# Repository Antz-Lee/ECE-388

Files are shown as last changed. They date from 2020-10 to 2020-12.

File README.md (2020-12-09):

# Volt-Meter-Project
Creating a voltmeter that displays the input voltage on an LCD display by using an ATmega328pb chip. The link below is a youtube video that focuses 
on the structure behind building a Voltmeter with an Atmega328PB microchip. The video also contains a live demo of the voltmeter that displays the 
voltage value of 9V batteries connected in series with a max voltage of 36Volts. 

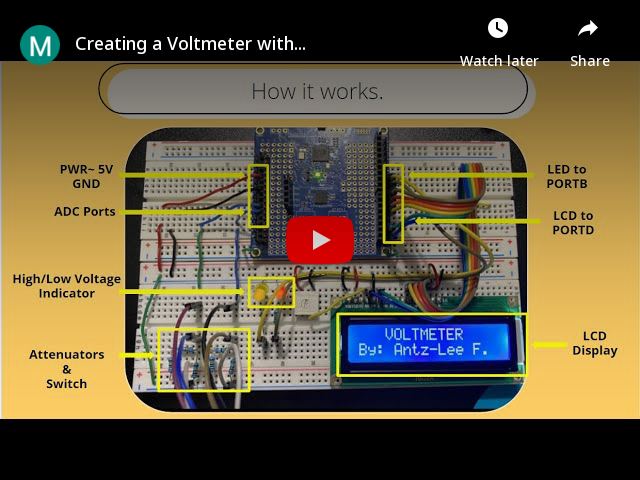
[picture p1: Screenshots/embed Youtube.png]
Watch the video (https://www.youtube.com/watch?v=6kzmSNdP678&ab_channel=Antz-LeeFrancois)


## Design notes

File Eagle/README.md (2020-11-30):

# Schematic and Board Layout
The schematic layout created on the EAGLE program. In regards, to the PCB Layout. the 16x2 LCD desplay isnt 
mounted directly onto the board, however, it will use connect cables so it could be applicable to be mounted on a frame.
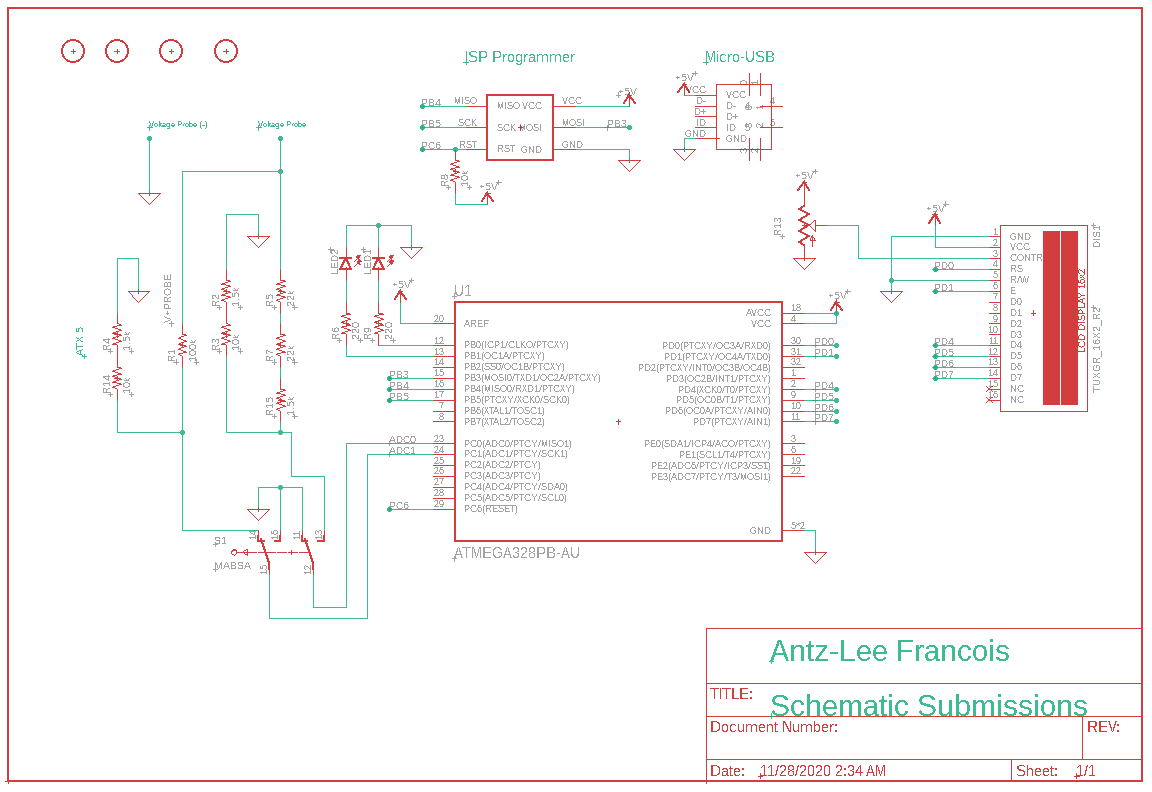
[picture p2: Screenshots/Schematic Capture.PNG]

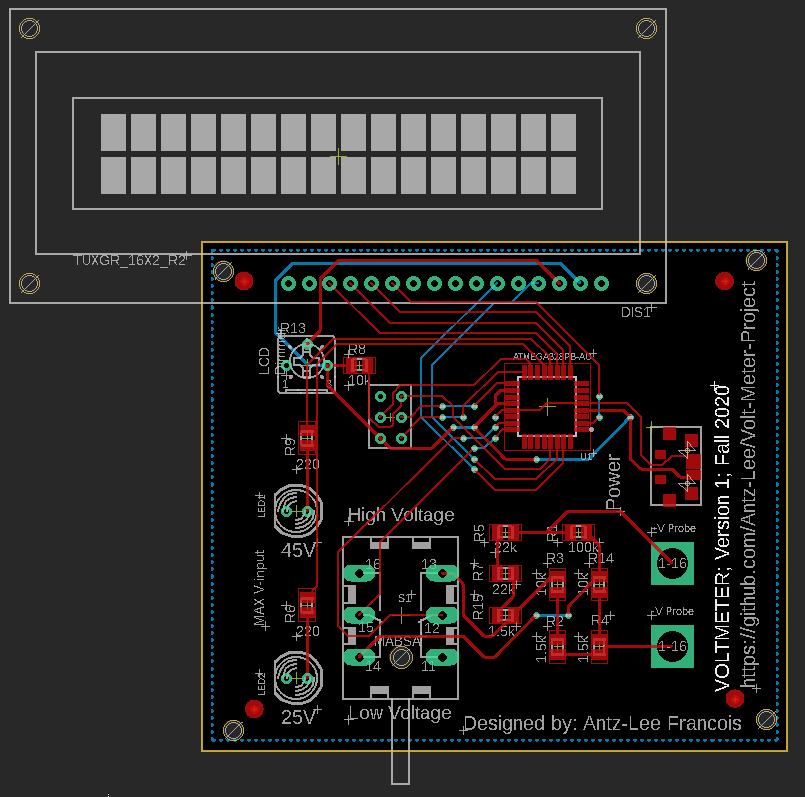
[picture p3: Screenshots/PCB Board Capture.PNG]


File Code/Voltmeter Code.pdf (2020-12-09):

...ithub\Github-Projects\Volt Meter Project\Code\Volt\main.c | 1
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
#include <stdlib.h>

#include <avr/io.h>

#include <stdint.h>

#include <avr/delay.h>

#include <string.h>

#define _BV(n) (1 << n)

#define F_CPU 4000000

#define LED5x PB1

#define LED10x PB0

#define LCD_Port PORTD | //Define LCD Port (PORTA, PORTB, PORTC, PORTD)

#define LCD_DPin DDRD | //Define 4-Bit Pins (PD4-PD7 at PORT D)

#define RSPIN PD0 | //RS Pin

#define ENPIN PD1 | //E Pin

uint16_t adc_read(uint16_t adcx); | // Allows the ADC ports to be read
void adc_init(); | // Enables the ADC port
void LCD_Init (void); | // Enables the LCD
void LCD_Clear(); | // CLears LCD screen and puts LCD
cursor at line 1
void LCD_Print (char *str); | // Prints string on LCD
void LCD_LineJmp( unsigned char cmnd ); | // Allows LCD Cursor to position at
line 1/2
void LED (char *command ); | // LED commands

int main(void)
{
adc_init(); | // Enables the ADC port
LED("Enable"); | // Enables the LED
LCD_Init(); | // Enables the LCD

// Setting variables
volatile uint16_t Vread10x = 0; volatile uint16_t Vread5x = 0;

volatile uint16_t ADC0;
volatile uint16_t ADC1;

// Setting I.D variables
volatile double Vres = 5.0/1024;
volatile double Error = .88; //0.9253382438;

// Voltage difference
volatile double Vmeas10x, Vmeas5x;

while(1)
{
// Setting the ADC read out pin Vread10x = adc_read(0);

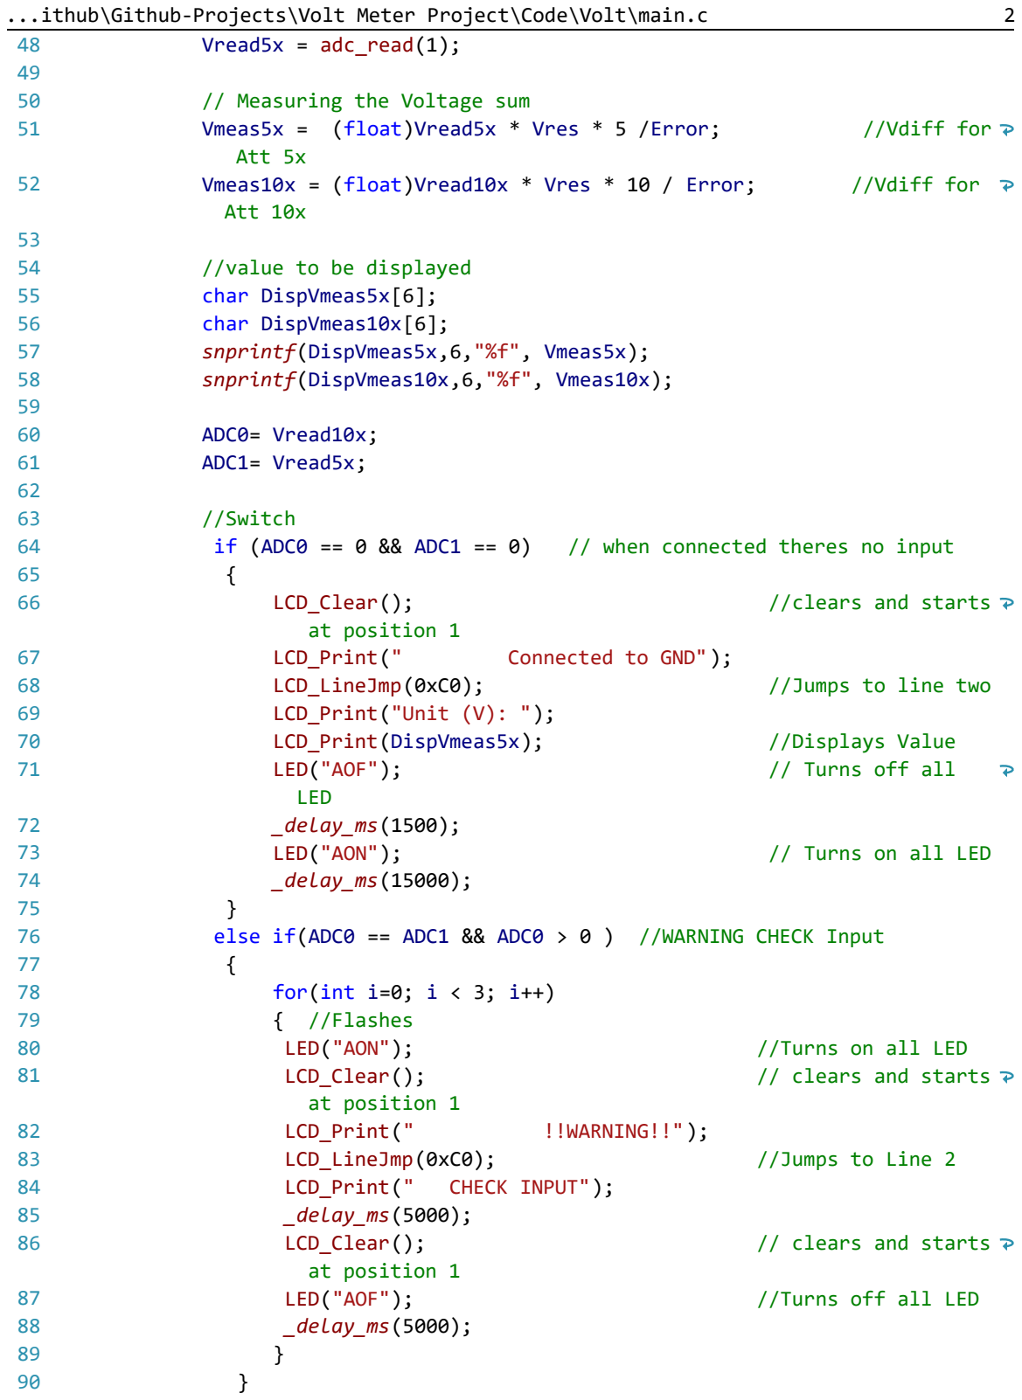
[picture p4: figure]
...ithub\Github-Projects\Volt Meter Project\Code\Volt\main.c; Vread5x = adc_read(1);; // Measuring the Voltage sum; Att 5x; Att 10x; //value to be displayed char DispVmeas5x[6]; char DispVmeas10x[6]; snprintf(DispVmeas5x,6,"%f", Vmeas5x); snprintf(DispVmeas10x,6,"%f", Vmeas10x);; ADC0= Vread10x; ADC1= Vread5x;; //Switch; LCD_Clear();; //clears and starts; at position 1; LCD_Print("; Connected to GND");; LCD_LineJmp(0xC0);; //Jumps to line two; LCD_Print("Unit (V): ");; LCD_Print(DispVmeas5x);; //Displays Value; LED("AOF");; // Turns off all; LED _delay_ms(1500);; LED("AON");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

Vmeas5x = (float)Vread5x * Vres * 5 /Error; | //Vdiff for
Vmeas10x = (float)Vread10x * Vres * 10 / Error; | //Vdiff for
if (ADC0 == 0 && ADC1 == 0) | // when connected theres no input

else if(ADC0 == ADC1 && ADC0 > 0 ) //WARNING CHECK Input

...ithub\Github-Projects\Volt Meter Project\Code\Volt\main.c | 3
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
else if(ADC0 > 0 && ADC1 < ADC0) //10x Position
{
LED("Atx10"); | //Turns on 10x LED
LCD_Clear(); | // clears and
starts at position 1
LCD_Print(" | HighVoltage <45V");
LCD_LineJmp(0xC0); | //jumps to line 2
LCD_Print("Unit (V): ");
LCD_Print(DispVmeas10x); | //Displays Value
_delay_ms(15000);
}
else //if(ADC1 > 0 && ADC1 > ADC0)
{ | //5x Position
LED("Atx5"); | // Turn on 5x LED
LCD_Clear(); | // clears and
starts at position 1
LCD_Print(" | Low Voltage <25V");
LCD_LineJmp(0xC0); | //jumps to line
two
LCD_Print("Unit (V): ");
LCD_Print(DispVmeas5x); | // Displays Value
_delay_ms(15000);
}
}
}

void LED (char *command )
{
if (command == "Enable")
{
DDRB |= _BV(LED10x);
DDRB |= _BV(LED5x);
}
else if(command == "Atx10")
{
PORTB &= ~(1<<LED5x); | // Turns off Low Voltage Light
PORTB |= _BV(LED10x); | //turns on High Voltage LED
}
else if (command == "Atx5")
{
PORTB &= ~(1<<LED10x); | //turns off High Voltage LED
PORTB |= _BV(LED5x); | // Turns on Low Voltage Light
}
else if(command == "AOF")
{
PORTB &= ~(1<<LED10x); | //turns off High Voltage LED
PORTB &= ~(1<<LED5x); | // Turns off Low Voltage Light
}
else if(command == "AON")

...ithub\Github-Projects\Volt Meter Project\Code\Volt\main.c | 4
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
PORTB |= _BV(LED10x); | //turns on High Voltage LED
PORTB |= _BV(LED5x); | //turns on Low Voltage LED
}
else if(command == "Blink")
{
PORTB &= ~(1<<LED10x); | //turns off High Voltage LED
PORTB &= ~(1<<LED5x); | // Turns off Low Voltage Light
_delay_ms(1500);
PORTB |= _BV(LED10x); | //turns on High Voltage LED
PORTB |= _BV(LED5x); | //turns on Low Voltage LED
}
else
{
return 0;
}
}

void LCD_Init (void)
{
LCD_DPin = 0xFF; | //Control LCD Pins (D4-D7)
_delay_ms(15); | //Wait before LCD activation
LCD_LineJmp(0x02); //4-Bit Control
LCD_LineJmp(0x28); | //Control Matrix @ 4-Bit
LCD_LineJmp(0x0c); | //Disable Cursor
LCD_LineJmp(0x06); | //Move Cursor
LCD_LineJmp(0x01); | //Clean LCD
_delay_ms(2);
}

void LCD_LineJmp( unsigned char cmnd )
{
LCD_Port = (LCD_Port & 0x0F) | (cmnd & 0xF0);
LCD_Port &= ~ (1<<RSPIN);
LCD_Port |= (1<<ENPIN);
_delay_us(1);
LCD_Port &= ~ (1<<ENPIN);
_delay_us(200);
LCD_Port = (LCD_Port & 0x0F) | (cmnd << 4);
LCD_Port |= (1<<ENPIN);
_delay_us(1);
LCD_Port &= ~ (1<<ENPIN);
_delay_ms(2);
}

void LCD_Clear()
{
LCD_LineJmp (0x01); | //Clear LCD
_delay_ms(2); | //Wait to clean LCD

...ithub\Github-Projects\Volt Meter Project\Code\Volt\main.c | 5
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
LCD_LineJmp (0x80); //Move to Position Line 1, Position 1 }

void LCD_Print (char *str)
{
int i;
for(i=0; str[i]!=0; i++ )
{
LCD_Port = (LCD_Port & 0x0F) | (str[i] & 0xF0);
LCD_Port |= (1<<RSPIN);
LCD_Port|= (1<<ENPIN);
_delay_us(1);
LCD_Port &= ~ (1<<ENPIN);
_delay_us(200);
LCD_Port = (LCD_Port & 0x0F) | (str[i] << 4);
LCD_Port |= (1<<ENPIN);
_delay_us(1);
LCD_Port &= ~ (1<<ENPIN);
_delay_ms(2);
}
}

// Enables
void adc_init()
{
ADMUX = (1<<REFS0) | (0<<REFS1);
// ADC Enable and prescaler of 128
// 8000000/128 = 62500
ADCSRA = (1<<ADEN)|(1<<ADPS2)|(1<<ADPS1)|(1<<ADPS0); }

// reads the ADC port
uint16_t adc_read(uint16_t adcx)
{
ADMUX &= 0xf0;
ADMUX |= adcx;

ADCSRA |= _BV(ADSC);
while( ADCSRA & _BV(ADSC) );

return (double)ADC;
}

/*//Write on a specific location
void LCD_Printpos (char row, char pos, char *str) {
if (row == 0 && pos<16)
LCD_LineJmp((pos & 0x0F)|0x80);

...ithub\Github-Projects\Volt Meter Project\Code\Volt\main.c | 6
235
236
237
238
239
240
241

else if (row == 1 && pos<16) LCD_LineJmp((pos & 0x0F)|0xC0); LCD_Print(str);
} */

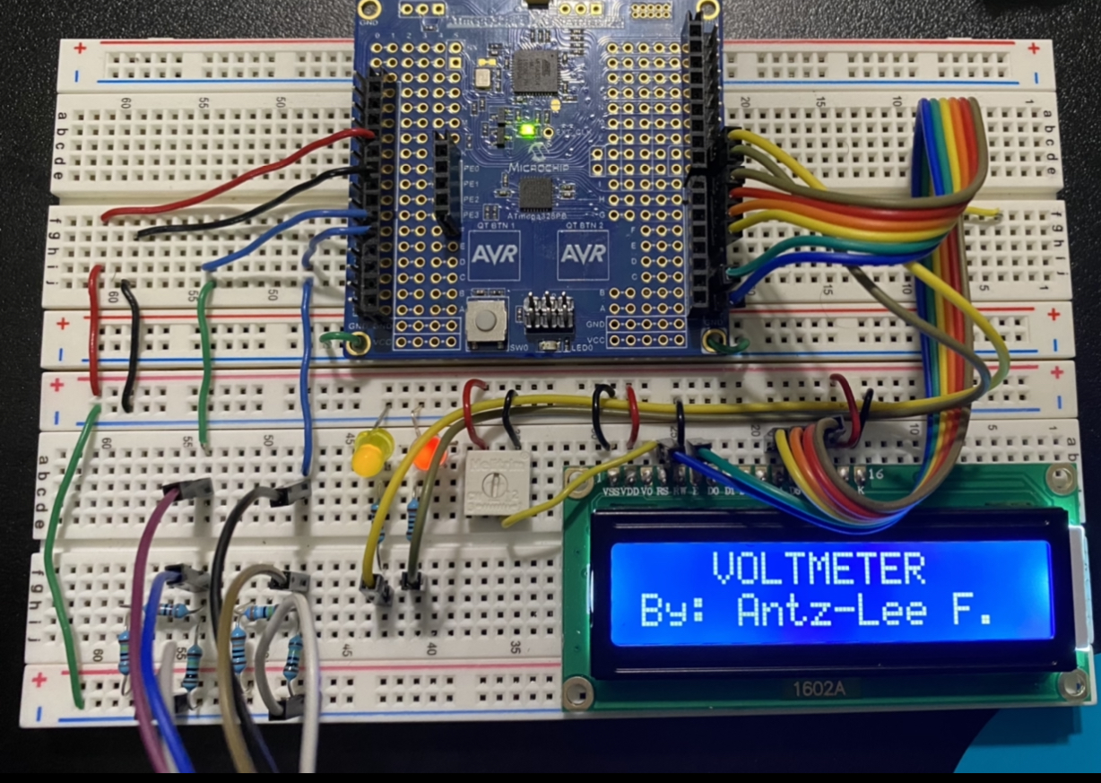
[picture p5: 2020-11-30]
Screenshots/Volt meter by Antz-Lee.jpg

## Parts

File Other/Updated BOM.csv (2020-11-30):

Qty | Value | Device | Package | Parts | Description | Unit Price x1 | Unit Price x10 | Unit Price x100 | Unit Price x1000 | Website
1 | 3p2t | 255SB | 255SB | S1 | SLIDING SWITCH |  | $0.60 | $0.50 | $0.38 | https://www.digikey.com/en/products/detail/c-k/SS-12D07-VG-4-NS-GA-PA/2747177
4 | 1M | R-US_0411/15 | 0411/15 | R1, R3, R6, R8 | RESISTOR, American symbol
1 | 2040002-1 | 2040002-1 | TE_2040002-1 | J1 | Conn USB Type B RCP 5 POS 0.65mm Solder RA SMD 5 Terminal 1 Port T/R Check prices |  | US$0.055331 | US$0.040337 | US$0.034829 | https://lcsc.com/product-detail/USB-Connectors_Jing-Extension-of-the-Electronic-Co-C77238_C77238.html
1 | ATMEGA328PB-AU | ATMEGA328PB-AU | QFP80P900X900X120-32N | U1 | ATmega Series 20 MHz 32 KB Flash 2 KB SRAM 8-Bit Microcontroller - TQFP-32 |  | US$1.35 | US$1.181667 | US$1.126667 | https://lcsc.com/product-detail/MICROCHIP_MICROCHIP_ATMEGA328PB-AU_ATMEGA328PB-AU_C132230.html
1 | AVR-ISP | AVR-ISP | AVR-ISP | U$1 | Check prices |  | $0.95 | $0.95 | $0.95 | https://www.digikey.com/en/products/detail/adafruit-industries-llc/1465/5353649
1 | OLED_DD-9664FC-2AFLAT | OLED_DD-9664FC-2AFLAT | OLEDDISPLAY9664 | OLED1 | Densitron Display DD-9664FS-2A
2 | 10k | Resitor |  |  |  |  | US$0.061805 | US$0.057873 | US$0.047468 | https://lcsc.com/product-detail/Metal-Film-Resistor-TH_10KR-1002-1_C202434.html
3 | 1.5k | Resitor |  |  |  |  | US$0.005888 | US$0.004347 | US$0.004064 | https://lcsc.com/product-detail/Metal-Film-Resistor-TH_UNI-ROYAL-Uniroyal-Elec-MFR0W4F1501A50_C58620.html
1 | 100k | Resitor |  |  |  |  | US$0.006654 | US$0.006654 | US$0.004921 | https://lcsc.com/product-detail/Metal-Film-Resistor-TH_TA-I-Tech-RN16T29532F_C172602.html
2 | 22k | Resistor |  |  |  |  | US$0.007975 | US$0.007975 | US$0.00551 | https://lcsc.com/product-detail/Metal-Film-Resistor-TH_TyoHM-RN-1-4W-22K-F-T-B-A1_C410655.html

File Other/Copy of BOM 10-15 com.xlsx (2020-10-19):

Qty | Value | Device | Package | Parts | Description | Unit Price x1 | Unit Price x10 | Unit Price x100 | Unit Price x1000 | Website
1 |  | 255SB | 255SB | S1 | SLIDING SWITCH |  | $0.60 | $0.50 | $0.38 | https://www.digikey.com/en/products/detail/c-k/SS-12D07-VG-4-NS-GA-PA/2747177
5 | 115pF | C-US025-025X050 | C025-025X050 | C1, C2, C3, C4, C5 | CAPACITOR, American symbol
4 | 1M | R-US_0411/15 | 0411/15 | R1, R3, R6, R8 | RESISTOR, American symbol
1 | 2040002-1 | 2040002-1 | TE_2040002-1 | J1 | Conn USB Type B RCP 5 POS 0.65mm Solder RA SMD 5 Terminal 1 Port T/R Check prices |  | US$0.055331 | US$0.040337 | US$0.034829 | https://lcsc.com/product-detail/USB-Connectors_Jing-Extension-of-the-Electronic-Co-C77238_C77238.html
3 | 35pF | C-US025-025X050 | C025-025X050 | C6, C7, C8 | CAPACITOR, American symbol
2 | 4M | R-US_0411/15 | 0411/15 | R7, R9 | RESISTOR, American symbol
1 | 5k | POTENTIOMETER_PT-10S | PT-10S | R4 | Potentiometer |  | US$0.09565 | US$0.089533 | US$0.080683 | https://lcsc.com/product-detail/Precision-Potentiometer_BOCHEN-Chengdu-Guosheng-Tech-3296W-1-502_C118907.html
2 | 9M | R-US_0411/15 | 0411/15 | R2, R5 | RESISTOR, American symbol |  | US$0.267933 | US$0.209059 | US$0.200171 | https://lcsc.com/product-detail/High-Voltage-Resistor_KOA-Speer-Elec-RCR60CT52A106J_C202438.html
1 | ATMEGA328PB-AU | ATMEGA328PB-AU | QFP80P900X900X120-32N | U1 | ATmega Series 20 MHz 32 KB Flash 2 KB SRAM 8-Bit Microcontroller - TQFP-32 |  | US$1.35 | US$1.181667 | US$1.126667 | https://lcsc.com/product-detail/MICROCHIP_MICROCHIP_ATMEGA328PB-AU_ATMEGA328PB-AU_C132230.html
1 | AVR-ISP | AVR-ISP | AVR-ISP | U$1 | Check prices |  | $0.95 | $0.95 | $0.95 | https://www.digikey.com/en/products/detail/adafruit-industries-llc/1465/5353649
1 | OLED_DD-9664FC-2AFLAT | OLED_DD-9664FC-2AFLAT | OLEDDISPLAY9664 | OLED1 | Densitron Display DD-9664FS-2A
1 | TUXGR_20X2 | TUXGR_20X2 | TUXGR_20X2 | DIS1 | Tuxgraphics LCD display 20x2 characters reflective, without background light |  | US$2.96 | US$2.78 | US$2.691667 | https://lcsc.com/product-detail/LCD-Displays-Modules_LCM1602K-NSW-BBW_C83275.html

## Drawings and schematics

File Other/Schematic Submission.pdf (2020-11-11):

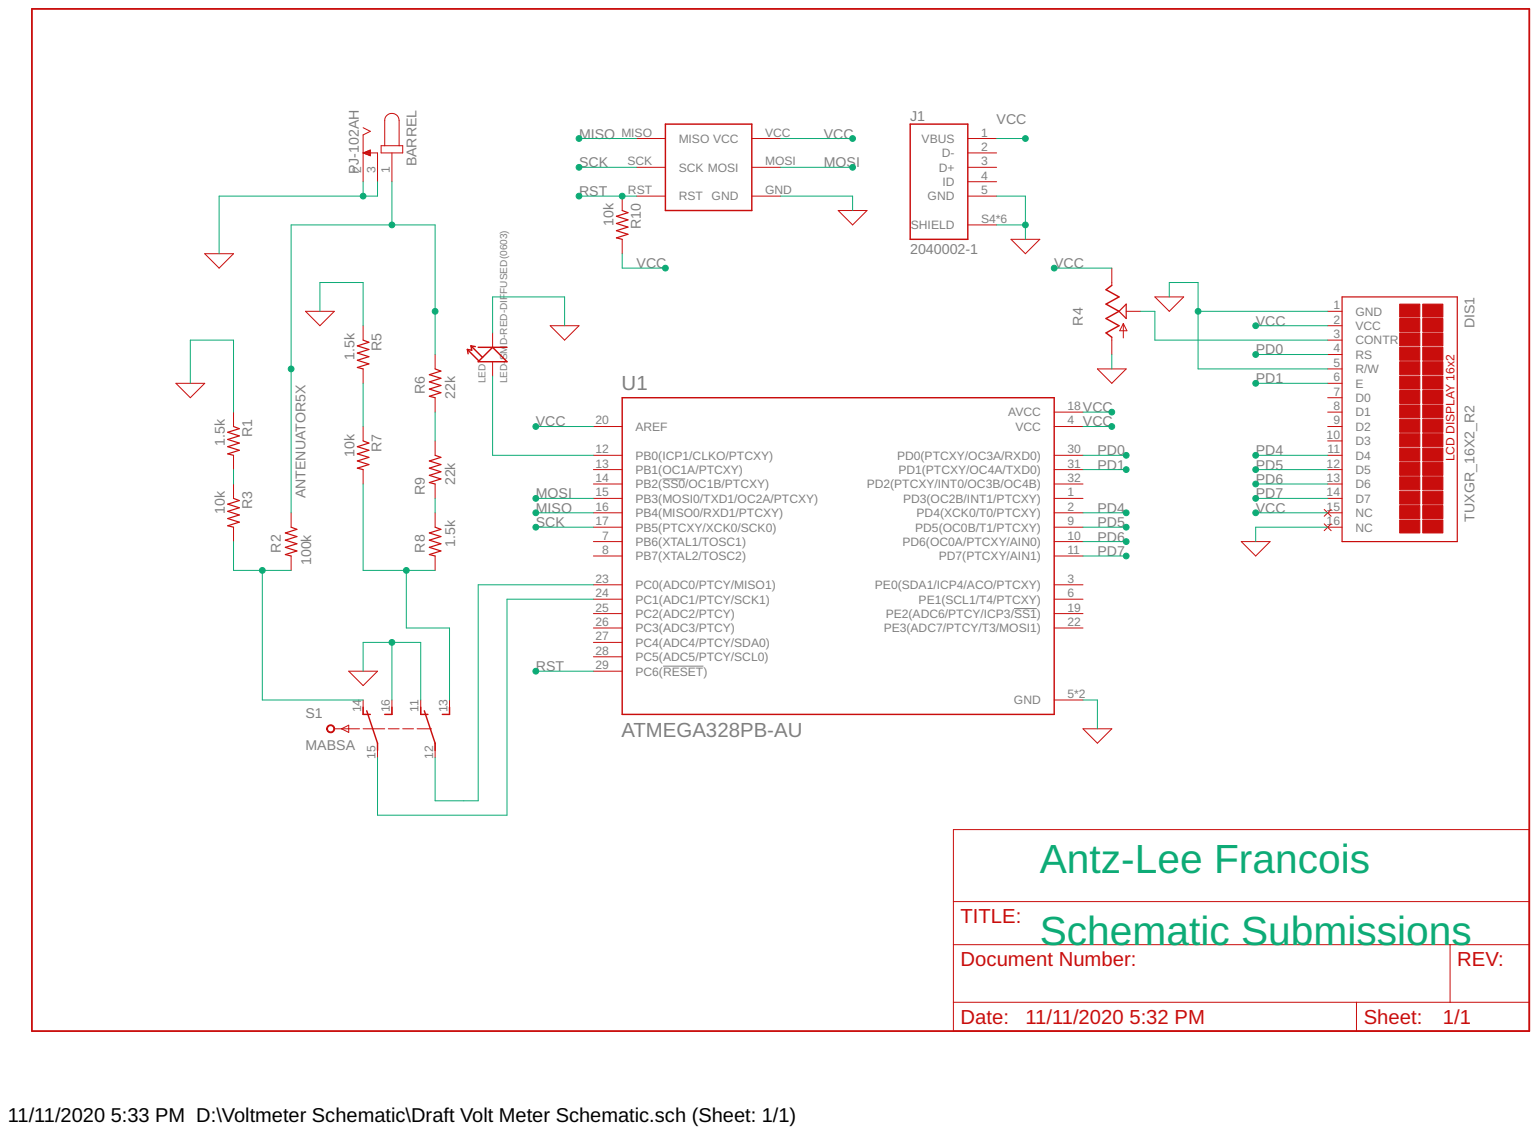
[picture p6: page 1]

LED-SMD-RED-DIFFUSED(0603)

Document Number: | REV:

Date: 11/11/2020 5:32 PM | Sheet: 1/1

11/11/2020 5:33 PM D:\Voltmeter Schematic\Draft Volt Meter Schematic.sch (Sheet: 1/1)

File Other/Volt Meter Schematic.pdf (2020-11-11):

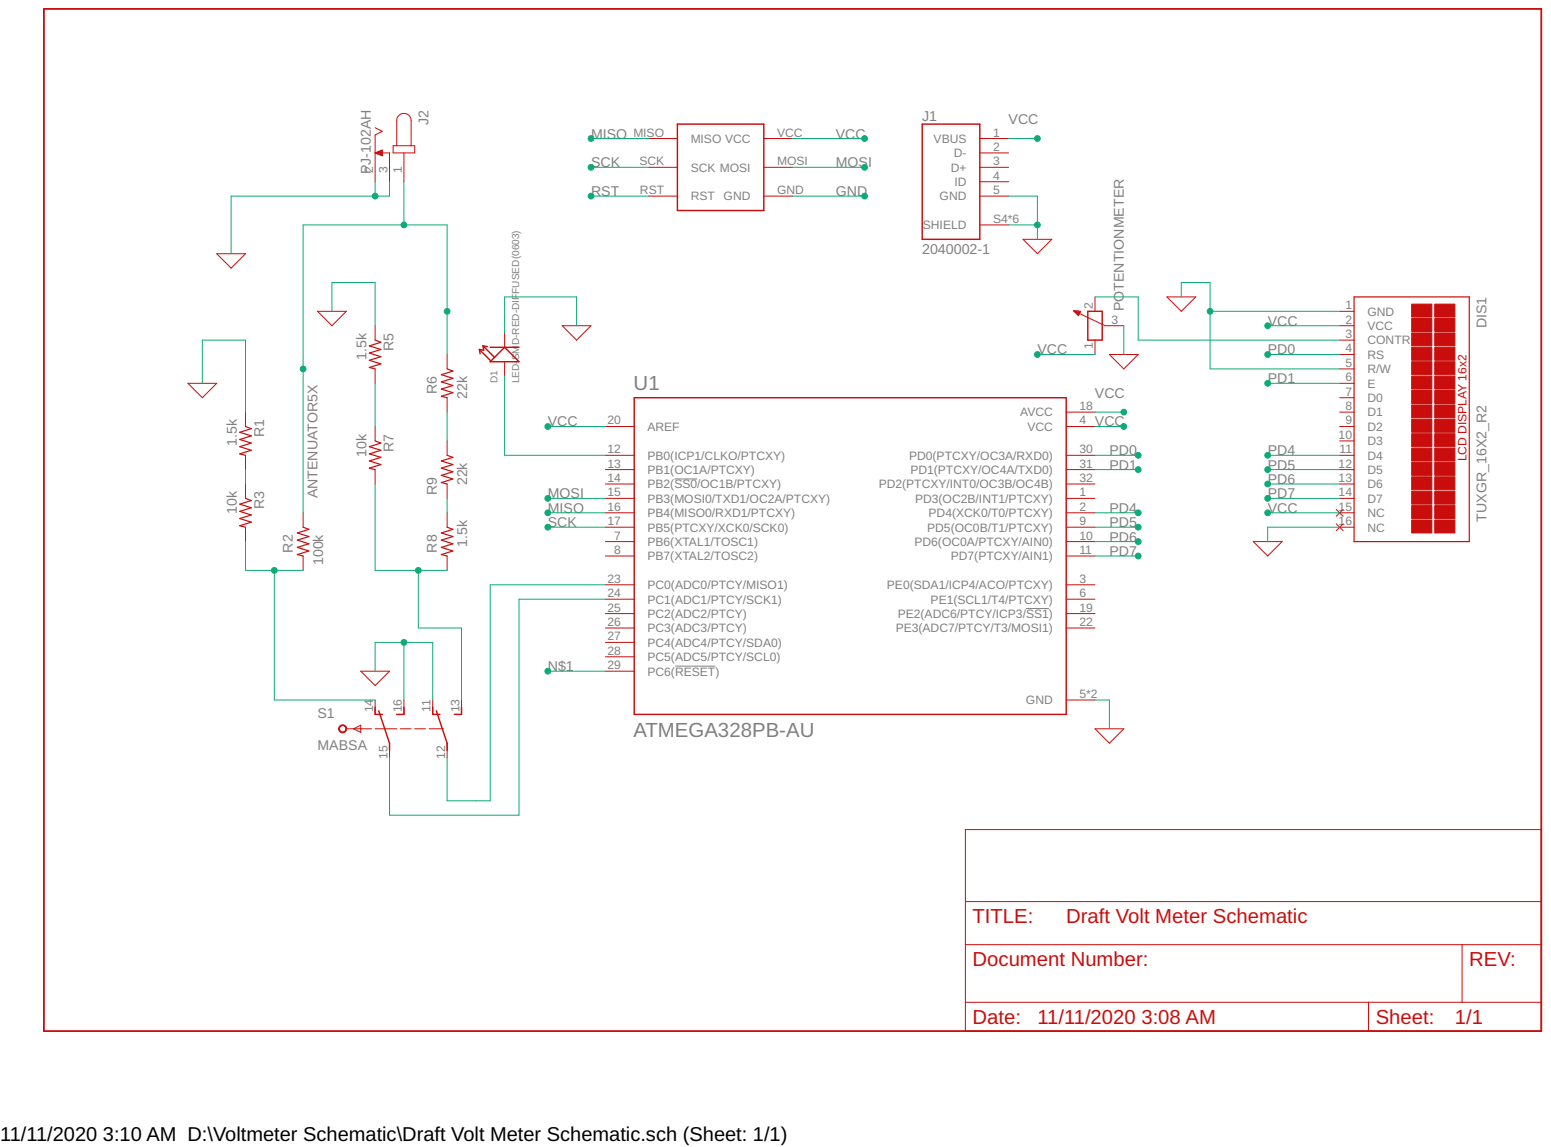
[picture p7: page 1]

LED-SMD-RED-DIFFUSED(0603)

Draft Volt Meter Schematic

Document Number: | REV:

Date: 11/11/2020 3:08 AM | Sheet: 1/1

11/11/2020 3:10 AM D:\Voltmeter Schematic\Draft Volt Meter Schematic.sch (Sheet: 1/1)

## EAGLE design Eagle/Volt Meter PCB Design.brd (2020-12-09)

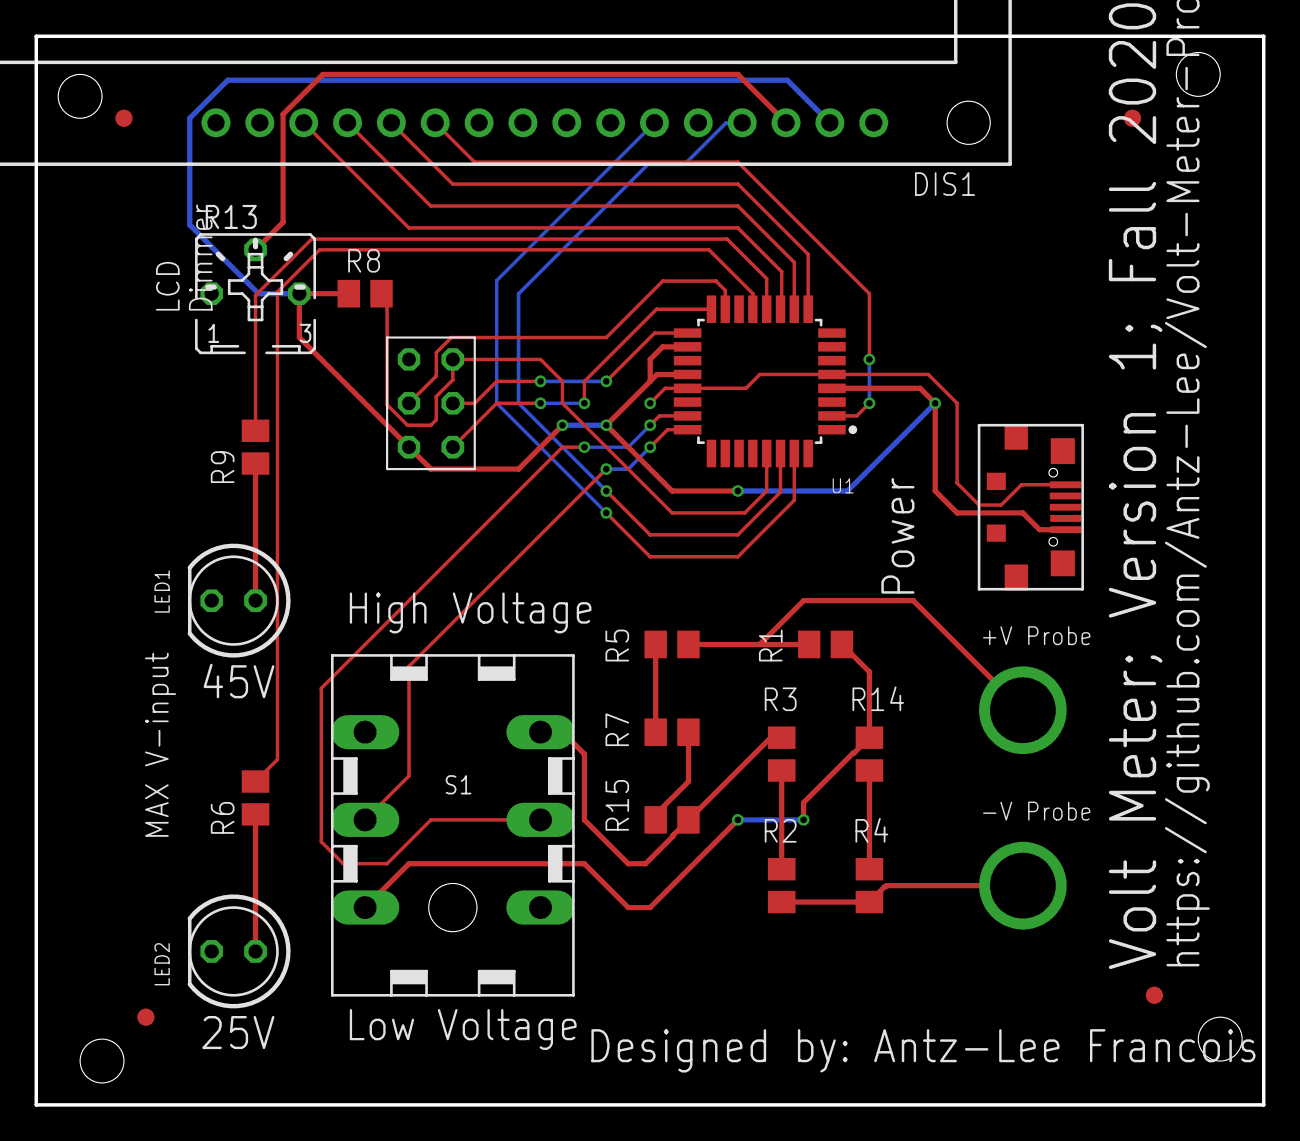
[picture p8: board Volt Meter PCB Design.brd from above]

Board: 2 copper layers, 71.1 x 61.9 mm, 23 parts (0 on the bottom side), 26 nets.

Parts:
AVR-ISP: AVR-ISP
DIS1: TUXGR_16X2_R2
LED1, LED2: LED5MM
MICROUSB1: MICROUSB1
R1: 100k; M0805
R2, R4, R15: 1.5k; M0805
R3, R8, R14: 10k; M0805
R5, R7: 22k; M0805
R6, R9: 220; M0805
R13: B25P
S1: MABSA
U1: ATMEGA328PB-AU; QFP80P900X900X120-32N
U$1, U$2, U$3, U$4: FIDUCIAL; FIDUCIAL_1MM

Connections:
0: AVR-ISP.GND, DIS1.1, DIS1.5, LED1.K, LED2.K, MICROUSB1.GND, R2.2, R4.2, R13.A, S1.11, S1.16, U1.5, U1.21
+5V: AVR-ISP.VCC, DIS1.2, MICROUSB1.VCC, R8.1, R13.E, U1.4, U1.18, U1.20
ADC0: S1.12, U1.23
ADC1: S1.15, U1.24
ATX5: R1.1, R14.1, S1.14
ATX10: R5.1, R7.2
HLED: LED1.A, R9.2
HLED_PWR: R9.1, U1.12
LCD_DIMMER: DIS1.3, R13.S
LLED: LED2.A, R6.2
LLED_PWR: R6.1, U1.13
unnamed: R4.1, R14.2
unnamed: R2.1, R3.2
unnamed: R7.1, R15.2
unnamed: R3.1, R15.1, S1.13
PB3: AVR-ISP.MOSI, U1.15
PB4: AVR-ISP.MISO, U1.16
PB5: AVR-ISP.SCK, U1.17
PC6: AVR-ISP.RST, R8.2, U1.29
PD0: DIS1.4, U1.30
PD1: DIS1.6, U1.31
PD4: DIS1.11, U1.2
PD5: DIS1.12, U1.9
PD6: DIS1.13, U1.10
PD7: DIS1.14, U1.11
V+PROBE: R1.2, R5.2

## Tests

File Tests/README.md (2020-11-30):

# Attenuator SPICE Model
Testing the attenuator to step down the input voltage so that the ADC ports on the ATmega can read. The MAX 
voltage input for the ADC Ports is 5V. So the Voltage input must be stepped down so it doesnt short the chip. 
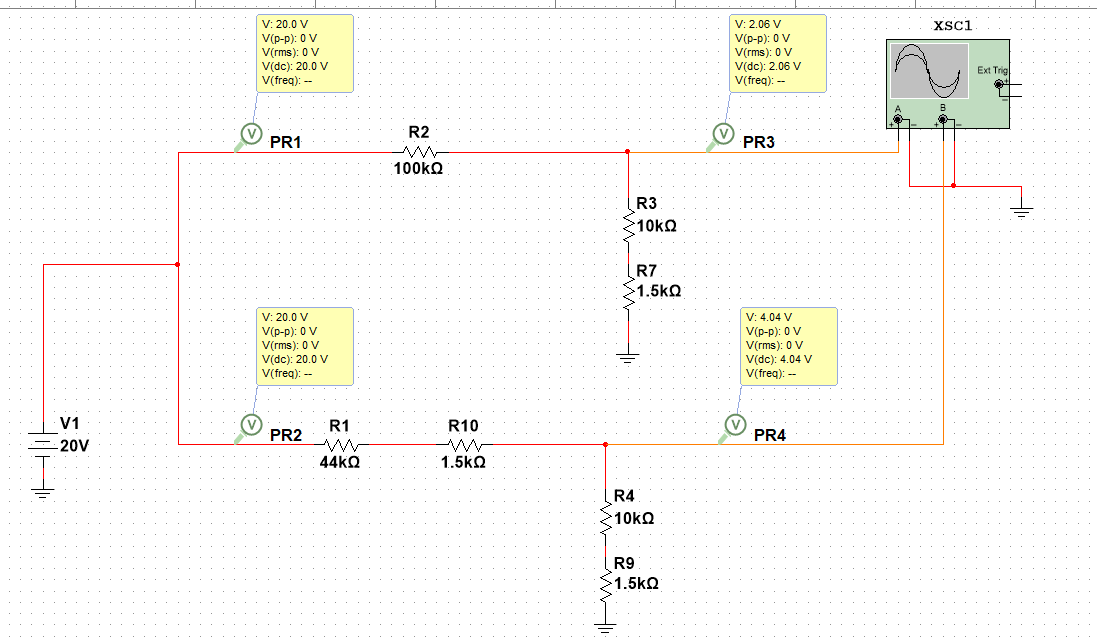
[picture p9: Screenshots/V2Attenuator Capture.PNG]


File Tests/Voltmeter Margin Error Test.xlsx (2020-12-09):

Voltmeter Margin Error Test
Test | 1 | 2 | 3 | 4 | 5 | 6 | 7 | AVG
Hacintosh | 0.41 | 0.839 | 4.995 | 4.033 | 0.332 | 0.668 | 0.517
REAL Voltmeter | 0.47 | 0.947 | 5.062 | 4.084 | 0.375 | 0.751 | 0.533
AVG | 0.8723 | 0.886 | 0.9868 | 0.9875 | 0.8853 | 0.8895 | 0.97 | 0.9253

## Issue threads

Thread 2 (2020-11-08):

Schematic Submission

timChase98, 2020-11-08:
- [ ] Review the submission guidelines [HERE](https://github.com/timChase98/388Example)
- [ ] All project files should be version controlled
- [ ] Schematics will only be graded if both the eagle files and rendered schematic are present in correct locations

Please address these issues and push your changes. Then create a new release, increment the tag and close this issue. I will review the changes and mark this as complete or reopen the issue with additional feedback.

Antz-Lee, 2020-11-11:
hey tim, i updated everything. Let me know if theres any issue. and i also sent you a few emails

timChase98, 2020-11-12:
- [ ] Don't use a barrel jack for your test connector
- [ ] Use power flags instead of named nets
- [ ] Add a pull up resistor to the reset line of the 328
- [ ] Add your project files to the github.

Antz-Lee, 2020-11-12:
tim what do you mean by power flags?  and by project files do you mean everything that ive been working on?

timChase98, 2020-11-12:
Use the symbols in the supply library for power.  Add your eagle files to the repo

Antz-Lee, 2020-11-13:
i fixed those symbols tim and updated everything.  I made a submission yesterday and Viall reminded me something about the design so i made an update on the submission!   Let me know if there's anything that I'm missing

Antz-Lee, 2020-11-16:
tim did my board get approved or no?

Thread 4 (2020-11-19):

Board Submission

timChase98, 2020-11-19:
- [x] Review the submission guidelines [HERE](https://github.com/timChase98/388Example)
- [x] All project files should be version controlled
- [x] Boards will not be graded unless both Eagle files and correctly generated Gerber files are present
- [x] All traces should hit the center of pads
- [x] Power traces should have a minimum width of 12 mil or run through a plane
- [x] Silkscreen labels must include
  - [x] Your Name
  - [x] Project Name
  - [x] Date
  - [x] Version/Rev
  - [x] Github Link
- [x] Check stock sheet for correct footprints for
  - [x] USB Connector
  - [x] Switch
  - [x] LEDs
  - [x] REsistors
  - [x] Pots
- [x] Your project would fit on a much smaller board
- [x] Placement of fiducials should be
  - [x] FID1 lower left
  - [x] FID2 upper left
  - [x] FID3 lower right

These are initial comments meant to guide you through the layout process.  I will not look at your board again until your schematic passes review.  This is to reduce the workload on you by limiting the number of times you need to relayout your board due to schematic errors.

Please address these issues and push your changes. Then create a new release, increment the tag and close this issue. I will review the changes and mark this as complete or reopen the issue with additional feedback.

Antz-Lee, 2020-11-30:
hey tim, i updated the submission and i also cleaned up the git hub so if you need anything just let me know.

Closed 2020-12-04.

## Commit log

2020-11-11 Gerber Files of Cam Data
    [copper_bottom.gbr, copper_top.gbr, gerber_job.gbrjob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]
2020-11-11 Schematic Submission
    Schematic Submission
2020-11-30 test 1, Folder Clean up and Projection SUbmission
    [Copy of BOM 10-15 com.xlsx, Draft Volt Meter Schematic.sch, Updated BOM.csv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]
2020-12-09 +Live Demo
    [Volt Meter PCB Design.brd, Voltmeter Margin Error Test.xlsx]
